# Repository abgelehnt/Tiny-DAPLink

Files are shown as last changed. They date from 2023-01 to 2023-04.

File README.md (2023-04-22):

# Tiny-DAPLink

> 小巧的使用CH552实现的DAPLink

详见[Tiny-DAPLink：开源CH552实现的CMSIS-DAP v2升级版](https://whycan.com/t_9365.html)

## 硬件设计

1. 下载按键需要超级小的两脚小龟按键，如果不重复下载调试，可以不焊
2. 整体需要包热缩管进行绝缘，不然手汗会造成数据异常

## DAT命令列表

使用任意串口工具发送特定的命令即可对Tiny-DAPLink进行相应的设置。

| 命令 | 描述 |
|:---|:---|
| DAT+RST | 重启调试器 |
| DAT+IAP | 进入调试器固件下载模式 |
| DAT+KEY? | 查询电容键盘映射的按键 |
| DAT+KEY=XX | 更改电容键盘映射的按键[USB CDC键盘键值表](3.Docs/Keyboard_HID.txt) |
| DAT+KEY=FF | 关闭电容键盘功能 |
| DAT+AUTHOR? | 查询作者信息 |
| DAT+KEY_FLASH | 刷新电容按键参数 |
| DAT+KEY_VALUE | 查看电容按键参数 |

## 注意事项

1. 一些不合格的数据线会使Type C接口外壳对地短路，使电容按键失效

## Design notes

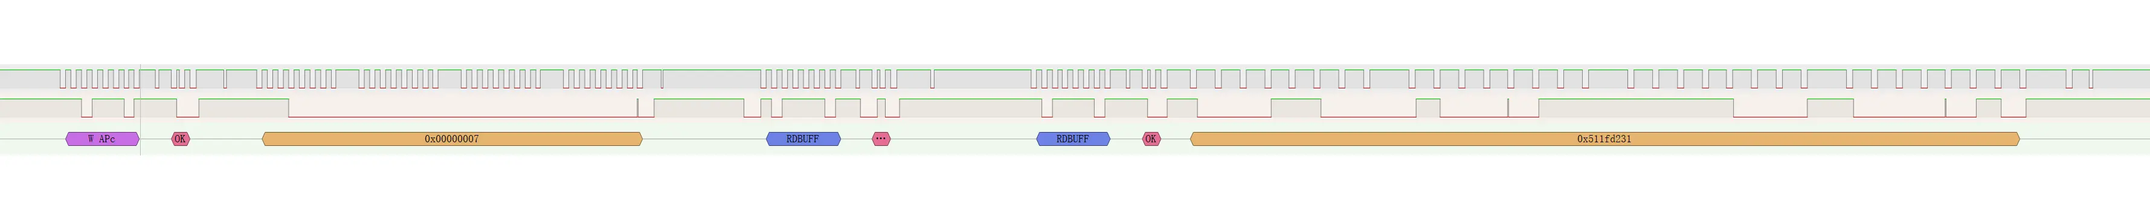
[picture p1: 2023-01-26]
4.Waves/d单次刷写.webp

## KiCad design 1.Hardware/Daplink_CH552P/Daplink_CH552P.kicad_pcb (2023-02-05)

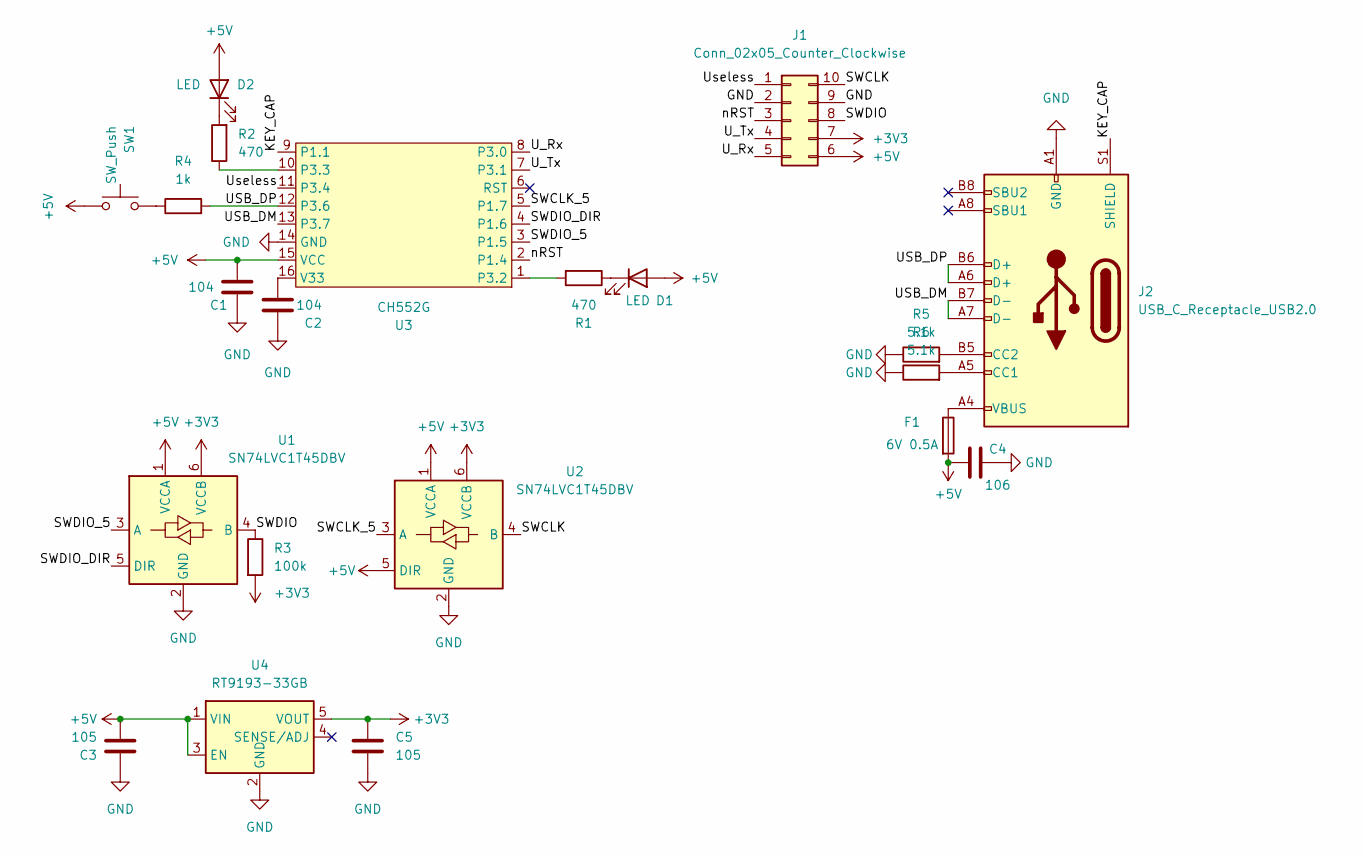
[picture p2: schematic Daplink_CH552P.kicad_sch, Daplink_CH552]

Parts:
C1, C2: 104; C_0603_1608Metric
C3, C5: 105; C_0603_1608Metric
C4: 106; C_0805_2012Metric
D1, D2: LED; LED_0603_1608Metric
F1: 6V 0.5A; Fuse_0603_1608Metric
J1: Conn_02x05_Counter_Clockwise; Connector_2.54mm_2_5P_SMD
J2: USB_C_Receptacle_USB2.0; USB_C_Receptacle_HRO_TYPE-C-31-M-12
R1, R2: 470; R_0603_1608Metric
R3: 100k; R_0603_1608Metric
R4: 1k; R_0603_1608Metric
R5, R6: 5.1k; R_0603_1608Metric
SW1: SW_Push; SW_SPST_B3U-1000P
U1, U2: SN74LVC1T45DBV; SOT-23-6
U3: CH552G; SOP-16_3.9x9.9mm_P1.27mm
U4: RT9193-33GB; TSOT-23-5

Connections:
+3V3: C5.2, J1.7, R3.2, U1.6 (VCCB), U2.6 (VCCB), U4.5 (VOUT)
+5V: C1.1, C3.1, C4.1, D1.2 (A), D2.2 (A), F1.2, J1.6, SW1.1, U1.1 (VCCA), U2.1 (VCCA), U2.5 (DIR), U3.15 (VCC), U4.1 (VIN), U4.3 (EN)
/KEY_CAP: J2.S1 (SHIELD), U3.9 (P1.1)
/SWCLK: J1.10, U2.4 (B)
/SWCLK_5: U2.3 (A), U3.5 (P1.7)
/SWDIO: J1.8, R3.1, U1.4 (B)
/SWDIO_5: U1.3 (A), U3.3 (P1.5)
/SWDIO_DIR: U1.5 (DIR), U3.4 (P1.6)
/USB_DM: J2.A7 (D-), J2.B7 (D-), U3.13 (P3.7)
/USB_DP: J2.A6 (D+), J2.B6 (D+), R4.2, U3.12 (P3.6)
/U_Rx: J1.5, U3.8 (P3.0)
/U_Tx: J1.4, U3.7 (P3.1)
/Useless: J1.1, U3.11 (P3.4)
/nRST: J1.3, U3.2 (P1.4)
GND: C1.2, C2.1, C3.2, C4.2, C5.1, J1.2, J1.9, J2.A1 (GND), J2.A12 (GND), J2.B1 (GND), J2.B12 (GND), R5.1, R6.1, U1.2 (GND), U2.2 (GND), U3.14 (GND), U4.2 (GND)
unnamed: C2.2, U3.16 (V33)
unnamed: D1.1 (K), R1.1
unnamed: D2.1 (K), R2.2
unnamed: F1.1, J2.A4 (VBUS), J2.A9 (VBUS), J2.B4 (VBUS), J2.B9 (VBUS)
unnamed: J2.A5 (CC1), R6.2
unnamed: J2.B5 (CC2), R5.2
unnamed: R1.2, U3.1 (P3.2)
unnamed: R2.1, U3.10 (P3.3)
unnamed: R4.1, SW1.2

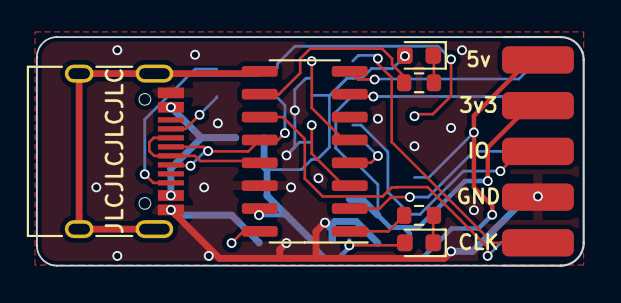
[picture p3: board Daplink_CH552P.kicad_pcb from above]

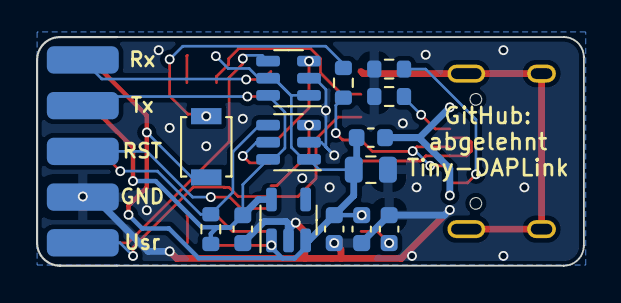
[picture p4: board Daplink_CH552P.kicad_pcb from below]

Board: 2 copper layers, 30.4 x 12.7 mm, 21 parts (15 on the bottom side), 24 nets.

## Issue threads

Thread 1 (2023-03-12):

电平转换电路简化的可能性

Maxwelltoo, 2023-03-12:
CH552系列芯片本身是支持3.3V输入的，直接将稳压输出的3.3V接入VCC，应该就可以省去两个SN74LVC1T45DBV，去掉SWDIO_DIR引脚。
考虑到接入IO的LED和键盘功能并非必须，是否可能将这些引脚全部省下来，进一步简化电路，使用更小封装的CH552E（刚好只有10个引脚）？

abgelehnt, 2023-03-13:
使用CH552E的话，串口引脚会和SPI引脚冲突（时序刷写用到了SPI）
如果退一步，不使用SPI加速刷写的话，使用3.3V电源输入的串口不支持115200波特率传输（16MHz主频），作为最常用的串口波特率，不支持的话整个串口功能都残废了。

Closed 2023-03-16.

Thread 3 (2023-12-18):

openocd 无法识别这个daplink

Retuze, 2023-12-18:
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

Retuze, 2023-12-18:
使用的硬件是梁山派 [daplink下载器](https://oshwhub.com/lengyuefeng/a7c57e6d86bd47789178df3fda9219dc)，使用原梁山派 daplink 固件在keil,openocd,pyocd均可识别、烧录，现使用本固件keil和pyocd能识别但是无法烧录，openocd 找不到daplink

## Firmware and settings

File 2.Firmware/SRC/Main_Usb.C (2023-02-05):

#include "CH552.H"
#include "Debug.H"
#include "DAP.h"
#include "Uart.h"
#include "Timer.H"
#include "AT.h"
#include "TouchKey.H"
#include "Keyboard.h"
#include "DataFlash.H"

#define Fullspeed 1
#define WINUSB 1
#define THIS_ENDP0_SIZE 64
#define ENDP4_IN_SIZE 8

UINT8X Ep0Buffer[THIS_ENDP0_SIZE] _at_ 0x0000;  //端点0 OUT&IN缓冲区，必须是偶地址

// EP1: UART
// extern UINT8X Uart_TxBuff0[]; // 端点1 OUT&IN 双缓冲区，长度0x100
// UINT8X Ep1BufferO[THIS_ENDP0_SIZE] _at_ 0x0040; //端点1 OUT双缓冲区,必须是偶地址 Not Change!!!!!!
// UINT8X Ep1BufferI[THIS_ENDP0_SIZE] _at_ 0x0080; //端点1 IN双缓冲区,必须是偶地址 Not Change!!!!!!

// EP2: DAP-CMD
//100,140,180,1C0
UINT8X Ep2BufferO[4 * THIS_ENDP0_SIZE] _at_ 0x0100; //端点2 OUT缓冲区

// EP3: DAP-ASK
//200,240,280,2C0
UINT8X Ep3BufferI[4 * THIS_ENDP0_SIZE] _at_ 0x0200; //端点3 IN双缓冲区,必须是偶地址

UINT8X Ep4Buffer[ENDP4_IN_SIZE+2] _at_ 0x0040; //端点4 IN双缓冲区,必须是偶地址

BOOL DAP_LED_BUSY;

UINT8I Ep2Oi, Ep2Oo;            //OUT 索引
UINT8I Ep3Ii, Ep3Io;            //IN 索引
UINT8I Ep3Is[DAP_PACKET_COUNT]; //发送包长

PUINT8 pDescr; //USB配置标志
BOOL Endp3Busy = 0;
UINT8I SetupReq, SetupLen, Ready, Count, UsbConfig;
#define UsbSetupBuf ((PUSB_SETUP_REQ)Ep0Buffer)

UINT8C DevDesc[] =
{
    0x12, 0x01, 0x10, 0x02, 0xEF, 0x02, 0x01, THIS_ENDP0_SIZE,
    0x28, 0x0D, 0x04, 0x02, 0x00, 0x01, 0x01, 0x02,
    0x03, 0x01
};
UINT8C CfgDesc[] =
{
//					wTotalLength	bNumInterfaces
    0x09,	0x02,	99,		0x00,	0x03,	0x01,	0x00,	0x80,	0xfa, //配置描述符
//	0x09,	0x02,	74,		0x00,	0x02,	0x01,	0x00,	0x80,	0xfa, //配置描述符

    //DAP
//			描述符	编号				端点数量 类码		子类码	协议码	字符串索引
    0x09,	0x04,	0x00,	0x00,	0x02,	0xff,	0x00,	0x00,	0x04, //接口描述符
//					端点号	Bulk	最大包大小		bInterval
    0x07,	0x05,	0x02,	0x02,	0x40,	0x00,	0x00, //端点描述符
    0x07,	0x05,	0x83,	0x02,	0x40,	0x00,	0x00,

	//CDC
    0x09,	0x04,	0x01,	0x00,	0x02,	0x02,	0x02,	0x01,	0x05,
	0x05,	0x24,	0x00,	0x10,	0x01,
    0x05,	0x24,	0x01,	0x00,	0x01,
    0x04,	0x24,	0x02,	0x02,
    0x05,	0x24,	0x06,	0x00,	0x01,
    0x07,	0x05,	0x01,	0x02,	0x40,	0x00,	0x00,
    0x07,	0x05,	0x81,	0x02,	0x40,	0x00,	0x00,

	// Keyboard
	0x09,	0x04,	0x02,	0x00,	0x01,	0x03,	0x01,	0x01,	0x06,	//接口描述符,键盘
	0x09,	0x21,	0x11,	0x01,	0x00,	0x01,	0x22,	0x3e,	0x00,	//HID类描述符
	0x07,	0x05,	0x84,	0x03,	8,		0x00,	0x20,					//端点描述符
};

UINT16I USB_STATUS = 0;
//cdc参数
UINT8I LineCoding[7] = {0x00, 0xe1, 0x00, 0x00, 0x00, 0x00, 0x08}; //初始化波特率为57600，1停止位，无校验，8数据位。

/*字符串描述符 略*/
// 语言描述符
UINT8C MyLangDescr[] = {0x04, 0x03, 0x09, 0x04};
// 厂家信息:ARM
UINT8C MyManuInfo[] = {0x08, 0x03, 'A', 0x00, 'R', 0x00, 'M', 0x00};
// 产品信息: DAPLink CMSIS-DAP
UINT8C MyProdInfo[] =
{
    36,
    0x03,
    'D', 0, 'A', 0, 'P', 0, 'L', 0, 'i', 0, 'n', 0, 'k', 0, ' ', 0,
    'C', 0, 'M', 0, 'S', 0, 'I', 0, 'S', 0, '-', 0, 'D', 0, 'A', 0,
    'P', 0
};

// 设备序列号
UINT8X SerNumber[] =
{
    0x12,
    0x03,
    '0', 0, '0', 0, '0', 0, '0', 0, '0', 0, '0', 0, '0', 0, '0', 0,
};

// 接口: CMSIS-DAP v2
UINT8C MyInterface[] =
{
    26,
    0x03,
    'C', 0, 'M', 0, 'S', 0, 'I', 0, 'S', 0, '-', 0, 'D', 0, 'A', 0,
    'P', 0, ' ', 0, 'v', 0, '2', 0
};
// 接口：USB-CDC
UINT8C CDC_String[] =
{
    30,
    0x03,
    'D', 0, 'A', 0, 'P', 0, 'L', 0, 'i', 0, 'n', 0, 'k', 0, '-', 0, 
	'C', 0, 'D', 0, 'C', 0, 'E', 0, 'x', 0, 't', 0
};
// 接口：DAPLink-Keyboard
UINT8C Keyboard_String[] =
{
    34,
    0x03,
    'D', 0, 'A', 0, 'P', 0, 'L', 0, 'i', 0, 'n', 0, 'k', 0, '-', 0, 
	'K', 0, 'e', 0, 'y', 0, 'b', 0, 'o', 0, 'a', 0, 'r', 0, 'd', 0
};

UINT8C USB_BOSDescriptor[] =
{
    0x05,                                      /* bLength */
    0x0F,                                      /* bDescriptorType */
    0x28, 0x00,                                /* wTotalLength */
    0x02,                                      /* bNumDeviceCaps */
    0x07, 0x10, 0x02, 0x00, 0x00, 0x00, 0x00,
    0x1C,                                      /* bLength */
    0x10,                                      /* bDescriptorType */
    0x05,                                      /* bDevCapabilityType */
    0x00,                                      /* bReserved */
    0xDF, 0x60, 0xDD, 0xD8,                    /* PlatformCapabilityUUID */
    0x89, 0x45, 0xC7, 0x4C,
    0x9C, 0xD2, 0x65, 0x9D,
    0x9E, 0x64, 0x8A, 0x9F,
    0x00, 0x00, 0x03, 0x06,    /* >= Win 8.1 *//* dwWindowsVersion*/
    0xAA, 0x00,                                /* wDescriptorSetTotalLength */
    0x20,                                      /* bVendorCode */
    0x00                                       /* bAltEnumCode */
};

UINT8C WINUSB_Descriptor[] =
{
    0x0A, 0x00,                                 /* wLength */
    0x00, 0x00,                                 /* wDescriptorType */
    0x00, 0x00, 0x03, 0x06,                     /* dwWindowsVersion*/
    0xAA, 0x00,                                 /* wDescriptorSetTotalLength */
    /* ... */
    0x08, 0x00,
    0x02, 0x00,
    0x00, 0x00,
    0xA0, 0x00,
    /* ... */
    0x14, 0x00,                                 /* wLength */
    0x03, 0x00,                                 /* wDescriptorType */
    'W', 'I', 'N', 'U', 'S', 'B', 0, 0,         /* CompatibleId*/
    0, 0, 0, 0, 0, 0, 0, 0,                     /* SubCompatibleId*/
    0x84, 0x00,                                 /* wLength */
    0x04, 0x00,                                 /* wDescriptorType */
    0x07, 0x00,                                 /* wPropertyDataType */
    0x2A, 0x00,                                 /* wPropertyNameLength */
    'D', 0, 'e', 0, 'v', 0, 'i', 0, 'c', 0, 'e', 0,
    'I', 0, 'n', 0, 't', 0, 'e', 0, 'r', 0, 'f', 0, 'a', 0, 'c', 0, 'e', 0,
    'G', 0, 'U', 0, 'I', 0, 'D', 0, 's', 0, 0, 0,
    0x50, 0x00,                                 /* wPropertyDataLength */
    '{', 0,
    'C', 0, 'D', 0, 'B', 0, '3', 0, 'B', 0, '5', 0, 'A', 0, 'D', 0, '-', 0,
    '2', 0, '9', 0, '3', 0, 'B', 0, '-', 0,
    '4', 0, '6', 0, '6', 0, '3', 0, '-', 0,
    'A', 0, 'A', 0, '3', 0, '6', 0, '-',
    0, '1', 0, 'A', 0, 'A', 0, 'E', 0, '4', 0, '6', 0, '4', 0, '6', 0, '3', 0, '7', 0, '7', 0, '6', 0,
    '}', 0, 0, 0, 0, 0,
};

/*HID类报表描述符*/
UINT8C KeyRepDesc[62] = {
	0x05,0x01,0x09,0x06,0xA1,0x01,0x05,0x07,
	0x19,0xe0,0x29,0xe7,0x15,0x00,0x25,0x01,
	0x75,0x01,0x95,0x08,0x81,0x02,0x95,0x01,
	0x75,0x08,0x81,0x01,0x95,0x03,0x75,0x01,
	0x05,0x08,0x19,0x01,0x29,0x03,0x91,0x02,
	0x95,0x05,0x75,0x01,0x91,0x01,0x95,0x06,
	0x75,0x08,0x26,0xff,0x00,0x05,0x07,0x19,
	0x00,0x29,0x91,0x81,0x00,0xC0
};

/*******************************************************************************
* Function Name  : USBDeviceInit()
* Description    : USB设备模式配置,设备模式启动，收发端点配置，中断开启
* Input          : None
* Output         : None
* Return         : None
*******************************************************************************/
void USBDeviceInit()
{
    IE_USB = 0;
    USB_CTRL = 0x00;        // 先设定USB设备模式
    UDEV_CTRL = bUD_PD_DIS; // 禁止DP/DM下拉电阻
#ifndef Fullspeed
    UDEV_CTRL |= bUD_LOW_SPEED; //选择低速1.5M模式
    USB_CTRL |= bUC_LOW_SPEED;
#else
    UDEV_CTRL &= ~bUD_LOW_SPEED; //选择全速12M模式，默认方式
    USB_CTRL &= ~bUC_LOW_SPEED;
#endif

    UEP0_DMA = Ep0Buffer;                                      //端点0数据传输地址
    UEP4_1_MOD &= ~(bUEP4_RX_EN | bUEP4_TX_EN);                //端点0单64字节收发缓冲区
    UEP0_CTRL = UEP_R_RES_ACK | UEP_T_RES_NAK;                 //OUT事务返回ACK，IN事务返回NAK

    UEP1_DMA = Uart_TxBuff0;									//端点1数据传输地址
    UEP4_1_MOD |= bUEP1_TX_EN | bUEP1_RX_EN;					//端点1发送接收使能
    UEP4_1_MOD |= bUEP1_BUF_MOD;								//端点1收发各双64字节缓冲区
    UEP1_CTRL = bUEP_AUTO_TOG | UEP_T_RES_NAK | UEP_R_RES_ACK; 					//端点1，IN事务返回NAK，OUT返回ACK

    UEP2_DMA = Ep2BufferO;                                     //端点2数据传输地址
    UEP3_DMA = Ep3BufferI;                                     //端点2数据传输地址
    UEP2_3_MOD |= (bUEP3_TX_EN | bUEP2_RX_EN);                   //端点2发送接收使能
    UEP2_3_MOD &= ~(bUEP2_BUF_MOD | bUEP3_BUF_MOD);            //端点2收发各64字节缓冲区
    UEP2_CTRL = bUEP_AUTO_TOG | UEP_T_RES_NAK | UEP_R_RES_ACK; //端点2自动翻转同步标志位，IN事务返回NAK，OUT返回ACK
    UEP3_CTRL = bUEP_AUTO_TOG | UEP_T_RES_NAK | UEP_R_RES_NAK;//端点3自动翻转同步标志位，IN事务返回NAK，OUT返回NACK

    UEP4_1_MOD |= bUEP4_TX_EN; // 端点4发送使能

    USB_DEV_AD = 0x00;
    USB_CTRL |= bUC_DEV_PU_EN | bUC_INT_BUSY | bUC_DMA_EN; // 启动USB设备及DMA，在中断期间中断标志未清除前自动返回NAK
    UDEV_CTRL |= bUD_PORT_EN;                              // 允许USB端口
    USB_INT_FG = 0xFF;                                     // 清中断标志
    USB_INT_EN = bUIE_SUSPEND | bUIE_TRANSFER | bUIE_BUS_RST;
    IE_USB = 1;
}

typedef void( *goISP)( void );
goISP ISP_ADDR=0x3800;

void DeviceInterrupt(void) interrupt INT_NO_USB //USB中断服务程序,使用寄存器组1
{
    UINT8 len;
    if (UIF_TRANSFER) //USB传输完成标志
    {
        switch (USB_INT_ST & (MASK_UIS_TOKEN | MASK_UIS_ENDP))
        {
        case UIS_TOKEN_OUT | 2: //endpoint 2# 端点批量下传 DAP-CMD
            if (U_TOG_OK)         // 不同步的数据包将丢弃
            {
                Ep2Oi += 64;
                UEP2_DMA_L = Ep2Oi;
            }
            break;

        case UIS_TOKEN_IN | 3: //endpoint 3# 端点批量上传 DAP_ASK
            Endp3Busy = 0;
            UEP3_T_LEN = 0;      //预使用发送长度一定要清空
            UEP3_CTRL = UEP3_CTRL & ~ MASK_UEP_T_RES | UEP_T_RES_NAK; //默认应答NAK
            break;

        case UIS_TOKEN_IN | 1: //endpoint 1# 端点批量上传 CDC
			UEP1_T_LEN = 0;
			UEP1_CTRL = UEP1_CTRL & ~ MASK_UEP_T_RES | UEP_T_RES_NAK;
			USB_CDC_PushData();
            break;

        case UIS_TOKEN_OUT | 1: //endpoint 1# 端点批量下传 CDC
            if (U_TOG_OK)         // 不同步的数据包将丢弃
            {
				USB_CDC_GetData();
            }
            break;
		case UIS_TOKEN_IN | 4: //endpoint 1# 端点中断上传
			UEP4_T_LEN = 0;
			UEP4_CTRL ^= bUEP_T_TOG;
			UEP4_CTRL = UEP4_CTRL & ~ MASK_UEP_T_RES | UEP_T_RES_NAK;           //默认应答NAK
			Keyboard_Flag = 1;
			break;

        case UIS_TOKEN_SETUP | 0: //SETUP事务
            len = USB_RX_LEN;
            if (len == (sizeof(USB_SETUP_REQ)))
            {
                SetupLen = UsbSetupBuf->wLengthL;
                if (UsbSetupBuf->wLengthH)
                    SetupLen = 0xFF; // 限制总长度
                len = 0;           // 默认为成功并且上传0长度
                SetupReq = UsbSetupBuf->bRequest;
                switch (UsbSetupBuf->bRequestType & USB_REQ_TYP_MASK)
                {
					case USB_REQ_TYP_STANDARD:
						switch (SetupReq) //请求码
						{
							case USB_GET_DESCRIPTOR:
								switch (UsbSetupBuf->wValueH){
								case 1:             //设备描述符
									pDescr = DevDesc; //把设备描述符送到要发送的缓冲区
									len = sizeof(DevDesc);
									break;
								case 2:             //配置描述符
									pDescr = CfgDesc; //把设备描述符送到要发送的缓冲区
									len = sizeof(CfgDesc);
									break;
								case 3: // 字符串描述符
									switch (UsbSetupBuf->wValueL)
									{
										case 0:
											pDescr = (PUINT8)(&MyLangDescr[0]);
											len = sizeof(MyLangDescr);
											break;
										case 1:
											pDescr = (PUINT8)(&MyManuInfo[0]);
											len = sizeof(MyManuInfo);
											break;
										case 2:
											pDescr = (PUINT8)(&MyProdInfo[0]);
											len = sizeof(MyProdInfo);
											break;
										case 3:
											HEX_TO_ASCII(SerNumber[2],*(UINT8C *)(0x3FFC)/16);
											HEX_TO_ASCII(SerNumber[4],*(UINT8C *)(0x3FFC)%16);
											HEX_TO_ASCII(SerNumber[6],*(UINT8C *)(0x3FFD)/16);
											HEX_TO_ASCII(SerNumber[8],*(UINT8C *)(0x3FFD)%16);
											
											HEX_TO_ASCII(SerNumber[10],*(UINT8C *)(0x3FFE)/16);
											HEX_TO_ASCII(SerNumber[12],*(UINT8C *)(0x3FFE)%16);
											HEX_TO_ASCII(SerNumber[14],*(UINT8C *)(0x3FFF)/16);
											HEX_TO_ASCII(SerNumber[16],*(UINT8C *)(0x3FFF)%16);
											
											pDescr = SerNumber;
											len = sizeof(SerNumber);
											break;
										case 4:
											pDescr = (PUINT8)(&MyInterface[0]);
											len = sizeof(MyInterface);
											break;
										case 5:
											pDescr = (PUINT8)(&CDC_String[0]);
											len = sizeof(CDC_String);
											break;
										case 6:
											pDescr = (PUINT8)(&Keyboard_String[0]);
											len = sizeof(Keyboard_String);
											break;
										default:
											len = 0xFF; // 不支持的字符串描述符
											break;
									}
									break;
								case 15:
									pDescr = (PUINT8)(&USB_BOSDescriptor[0]);
									len = sizeof(USB_BOSDescriptor);
									break;
								case 0x22:                                          //报表描述符
									if(UsbSetupBuf->wIndexL == 2)                   //接口0报表描述符
									{
										pDescr = KeyRepDesc;                        //数据准备上传
										len = sizeof(KeyRepDesc);
									}
									else
									{
										len = 0xff;           //本程序只有2个接口，这句话正常不可能执行
									}
									break;
								default:
									len = 0xff; //不支持的命令或者出错
									break;
							}
							break;
						case USB_SET_ADDRESS:
							SetupLen = UsbSetupBuf->wValueL; //暂存USB设备地址
							break;
						case USB_GET_CONFIGURATION:
							Ep0Buffer[0] = UsbConfig;
							if (SetupLen >= 1)
							{
								len = 1;
							}
							break;
						case USB_SET_CONFIGURATION:
							UsbConfig = UsbSetupBuf->wValueL;
							if (UsbConfig)
							{
								Ready = 1; //set config命令一般代表usb枚举完成的标志
							}
							break;
						case 0x0A:
							break;
						case USB_CLEAR_FEATURE:                                                       //Clear Feature
							if ((UsbSetupBuf->bRequestType & USB_REQ_RECIP_MASK) == USB_REQ_RECIP_ENDP) // 端点
							{
								switch (UsbSetupBuf->wIndexL)
								{
								case 0x82:
									UEP2_CTRL = UEP2_CTRL & ~(bUEP_T_TOG | MASK_UEP_T_RES) | UEP_T_RES_NAK;
									break;
								case 0x81:
									UEP1_CTRL = UEP1_CTRL & ~(bUEP_T_TOG | MASK_UEP_T_RES) | UEP_T_RES_NAK;
									break;
								case 0x02:
									UEP2_CTRL = UEP2_CTRL & ~(bUEP_R_TOG | MASK_UEP_R_RES) | UEP_R_RES_ACK;
									break;
								default:
									len = 0xFF; // 不支持的端点
									break;
								}
							}
							else
							{
								len = 0xFF; // 不是端点不支持
							}
							break;
						case USB_SET_FEATURE:                             /* Set Feature */
							if ((UsbSetupBuf->bRequestType & 0x1F) == 0x00) /* 设置设备 */
							{
								if ((((UINT16)UsbSetupBuf->wValueH << 8) | UsbSetupBuf->wValueL) == 0x01)
								{
									if (CfgDesc[7] & 0x20)
									{
										/* 设置唤醒使能标志 */
									}
									else
									{
										len = 0xFF; /* 操作失败 */
									}
								}
								else
								{
									len = 0xFF; /* 操作失败 */
								}
							}
							else if ((UsbSetupBuf->bRequestType & 0x1F) == 0x02) /* 设置端点 */
							{
								if ((((UINT16)UsbSetupBuf->wValueH << 8) | UsbSetupBuf->wValueL) == 0x00)
								{
									switch (((UINT16)UsbSetupBuf->wIndexH << 8) | UsbSetupBuf->wIndexL)
									{
									case 0x82:
										UEP2_CTRL = UEP2_CTRL & (~bUEP_T_TOG) | UEP_T_RES_STALL; /* 设置端点2 IN STALL */
										break;
									case 0x02:
										UEP2_CTRL = UEP2_CTRL & (~bUEP_R_TOG) | UEP_R_RES_STALL; /* 设置端点2 OUT Stall */
										break;
									case 0x81:
										UEP1_CTRL = UEP1_CTRL & (~bUEP_T_TOG) | UEP_T_RES_STALL; /* 设置端点1 IN STALL */
										break;
									default:
										len = 0xFF; /* 操作失败 */
										break;
									}
								}
								else
								{
									len = 0xFF; /* 操作失败 */
								}
							}
							else
							{
								len = 0xFF; /* 操作失败 */
							}
							break;
						case USB_GET_STATUS:
							pDescr = (PUINT8)&USB_STATUS;
							if (SetupLen >= 2)
							{
								len = 2;
							}
							else
							{
								len = SetupLen;
							}
							break;
						default:
							len = 0xff; //操作失败
							break;
                    }
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
void main(void)
{
    CfgFsys();   //CH559时钟选择配置
    mDelaymS(5); //修改主频等待内部晶振稳定,必加
   
    USBDeviceInit(); //USB设备模式初始化
	UART_Setup();
    P1_MOD_OC = P1_MOD_OC & ~(1 << 4);
    P1_DIR_PU = P1_DIR_PU | (1 << 4);
    P1_MOD_OC = P1_MOD_OC & ~(1 << 5);
    P1_DIR_PU = P1_DIR_PU | (1 << 5);
	
	//Timer2_Init();
	TK_Init( BIT4,1,0 );
	ReadDataFlash(0,1,&TargetKey);
	memset(Ep4Buffer,0,8);

	SAFE_MOD = 0x55;
	SAFE_MOD = 0xAA;
	WAKE_CTRL = bWAK_BY_USB | bWAK_RXD0_LO;	//USB or RXD0 can wake it up
	
	
    EA = 1;          //允许单片机中断
    UEP1_T_LEN = 0;  //预使用发送长度一定要清空
    UEP2_T_LEN = 0;  //预使用发送长度一定要清空
    Ready = 0;

    Ep2Oi = 0;
    Ep2Oo = 0;
    Ep3Ii = 0;
    Ep3Io = 0;
    Endp3Busy = 0;
	DAP_LED_BUSY = 0;
	LED_Timer = 0;
	

	
    while (!UsbConfig) {;};

    while (1)
    {
        DAP_Thread();

        if (Endp3Busy != 1 && Ep3Ii != Ep3Io){
            Endp3Busy = 1;
            UEP3_T_LEN = Ep3Is[0];//Ep3Io>>6];
            UEP3_DMA_L = Ep3Io;
            
            UEP3_CTRL = UEP3_CTRL & ~MASK_UEP_T_RES | UEP_T_RES_ACK; //有数据时上传数据并应答ACK
            Ep3Io += 64;
        }
		
		
		if(DAP_LED_BUSY)
		{
			LED = 1;
		}
		else
		{
			LED_Timer++;
			if(LED_Timer==0x09)
			{
				LED = 0;
			}else if(LED_Timer==0xFF)
			{
				LED_Timer = 0;
				LED = 1;
			}	
			TK_Measure();
		}

		LED2 = XBUS_AUX & (bUART0_TX | bUART0_RX);

		if(TO_IAP) {
			EA = 0;
			USB_CTRL = 0;
			UDEV_CTRL = 0x80;
			mDelaymS(100);
			(ISP_ADDR)();
		}
    }
}

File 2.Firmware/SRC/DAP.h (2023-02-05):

/*
 * Copyright (c) 2013-2017 ARM Limited. All rights reserved.
 *
 * SPDX-License-Identifier: Apache-2.0
 *
 * Licensed under the Apache License, Version 2.0 (the License); you may
 * not use this file except in compliance with the License.
 * You may obtain a copy of the License at
 *
 * www.apache.org/licenses/LICENSE-2.0
 *
 * Unless required by applicable law or agreed to in writing, software
 * distributed under the License is distributed on an AS IS BASIS, WITHOUT
 * WARRANTIES OR CONDITIONS OF ANY KIND, either express or implied.
 * See the License for the specific language governing permissions and
 * limitations under the License.
 *
 * ----------------------------------------------------------------------
 *
 * $Date:        1. December 2017
 * $Revision:    V2.0.0
 *
 * Project:      CMSIS-DAP Include
 * Title:        DAP.h Definitions
 *
 *---------------------------------------------------------------------------*/

#ifndef __DAP_H__
#define __DAP_H__

#include "CH552.H"
#include <stdio.h>
#include <string.h>
#include <intrins.h>

// DAP Firmware Version
#define DAP_FW_VER "2.0.0"

// DAP Command IDs
#define ID_DAP_Info 0x00U
#define ID_DAP_HostStatus 0x01U
#define ID_DAP_Connect 0x02U
#define ID_DAP_Disconnect 0x03U
#define ID_DAP_TransferConfigure 0x04U
#define ID_DAP_Transfer 0x05U
#define ID_DAP_TransferBlock 0x06U
#define ID_DAP_TransferAbort 0x07U
#define ID_DAP_WriteABORT 0x08U
#define ID_DAP_Delay 0x09U
#define ID_DAP_ResetTarget 0x0AU
#define ID_DAP_SWJ_Pins 0x10U
#define ID_DAP_SWJ_Clock 0x11U
#define ID_DAP_SWJ_Sequence 0x12U
#define ID_DAP_SWD_Configure 0x13U
#define ID_DAP_SWD_Sequence 0x1DU
#define ID_DAP_JTAG_Sequence 0x14U
#define ID_DAP_JTAG_Configure 0x15U
#define ID_DAP_JTAG_IDCODE 0x16U
#define ID_DAP_SWO_Transport 0x17U
#define ID_DAP_SWO_Mode 0x18U
#define ID_DAP_SWO_Baudrate 0x19U
#define ID_DAP_SWO_Control 0x1AU
#define ID_DAP_SWO_Status 0x1BU
#define ID_DAP_SWO_ExtendedStatus 0x1EU
#define ID_DAP_SWO_Data 0x1CU

#define ID_DAP_QueueCommands 0x7EU
#define ID_DAP_ExecuteCommands 0x7FU

// DAP Vendor Command IDs
#define ID_DAP_Vendor0 0x80U
#define ID_DAP_Vendor1 0x81U
#define ID_DAP_Vendor2 0x82U
#define ID_DAP_Vendor3 0x83U
#define ID_DAP_Vendor4 0x84U
#define ID_DAP_Vendor5 0x85U
#define ID_DAP_Vendor6 0x86U
#define ID_DAP_Vendor7 0x87U
#define ID_DAP_Vendor8 0x88U
#define ID_DAP_Vendor9 0x89U
#define ID_DAP_Vendor10 0x8AU
#define ID_DAP_Vendor11 0x8BU
#define ID_DAP_Vendor12 0x8CU
#define ID_DAP_Vendor13 0x8DU
#define ID_DAP_Vendor14 0x8EU
#define ID_DAP_Vendor15 0x8FU
#define ID_DAP_Vendor16 0x90U
#define ID_DAP_Vendor17 0x91U
#define ID_DAP_Vendor18 0x92U
#define ID_DAP_Vendor19 0x93U
#define ID_DAP_Vendor20 0x94U
#define ID_DAP_Vendor21 0x95U
#define ID_DAP_Vendor22 0x96U
#define ID_DAP_Vendor23 0x97U
#define ID_DAP_Vendor24 0x98U
#define ID_DAP_Vendor25 0x99U
#define ID_DAP_Vendor26 0x9AU
#define ID_DAP_Vendor27 0x9BU
#define ID_DAP_Vendor28 0x9CU
#define ID_DAP_Vendor29 0x9DU
#define ID_DAP_Vendor30 0x9EU
#define ID_DAP_Vendor31 0x9FU

#define ID_DAP_Invalid 0xFFU

// DAP Status Code
#define DAP_OK 0U
#define DAP_ERROR 0xFFU

// DAP ID
#define DAP_ID_VENDOR 1U
#define DAP_ID_PRODUCT 2U
#define DAP_ID_SER_NUM 3U
#define DAP_ID_FW_VER 4U
#define DAP_ID_DEVICE_VENDOR 5U
#define DAP_ID_DEVICE_NAME 6U
#define DAP_ID_CAPABILITIES 0xF0U
#define DAP_ID_TIMESTAMP_CLOCK 0xF1U
#define DAP_ID_SWO_BUFFER_SIZE 0xFDU
#define DAP_ID_PACKET_COUNT 0xFEU
#define DAP_ID_PACKET_SIZE 0xFFU

// DAP Host Status
#define DAP_DEBUGGER_CONNECTED 0U
#define DAP_TARGET_RUNNING 1U

// DAP Port
#define DAP_PORT_AUTODETECT 0U // Autodetect Port
#define DAP_PORT_DISABLED 0U   // Port Disabled (I/O pins in High-Z)
#define DAP_PORT_SWD 1U        // SWD Port (SWCLK, SWDIO) + nRESET
#define DAP_PORT_JTAG 2U       // JTAG Port (TCK, TMS, TDI, TDO, nTRST) + nRESET

// DAP SWJ Pins
#define DAP_SWJ_SWCLK_TCK 0 // SWCLK/TCK
#define DAP_SWJ_SWDIO_TMS 1 // SWDIO/TMS
#define DAP_SWJ_TDI 2       // TDI
#define DAP_SWJ_TDO 3       // TDO
#define DAP_SWJ_nTRST 5     // nTRST
#define DAP_SWJ_nRESET 7    // nRESET

#define DAP_SWJ_SWCLK_TCK_BIT 0x01 // SWCLK/TCK
#define DAP_SWJ_SWDIO_TMS_BIT 0x02 // SWDIO/TMS
#define DAP_SWJ_TDI_BIT 0x04       // TDI
#define DAP_SWJ_TDO_BIT 0x08       // TDO
#define DAP_SWJ_nTRST_BIT 0x20     // nTRST
#define DAP_SWJ_nRESET_BIT 0x80    // nRESET

// DAP Transfer Request
#define DAP_TRANSFER_APnDP (1U << 0)
#define DAP_TRANSFER_RnW (1U << 1)
#define DAP_TRANSFER_A2 (1U << 2)
#define DAP_TRANSFER_A3 (1U << 3)
#define DAP_TRANSFER_MATCH_VALUE (1U << 4)
#define DAP_TRANSFER_MATCH_MASK (1U << 5)
#define DAP_TRANSFER_TIMESTAMP (1U << 7)

// DAP Transfer Response
#define DAP_TRANSFER_OK (1U << 0)
#define DAP_TRANSFER_WAIT (1U << 1)
#define DAP_TRANSFER_FAULT (1U << 2)
#define DAP_TRANSFER_ERROR (1U << 3)
#define DAP_TRANSFER_MISMATCH (1U << 4)

// DAP SWO Trace Mode
#define DAP_SWO_OFF 0U
#define DAP_SWO_UART 1U
#define DAP_SWO_MANCHESTER 2U

// DAP SWO Trace Status
#define DAP_SWO_CAPTURE_ACTIVE (1U << 0)
#define DAP_SWO_CAPTURE_PAUSED (1U << 1)
#define DAP_SWO_STREAM_ERROR (1U << 6)
#define DAP_SWO_BUFFER_OVERRUN (1U << 7)

// Debug Port Register Addresses
#define DP_IDCODE 0x00U    // IDCODE Register (SW Read only)
#define DP_ABORT 0x00U     // Abort Register (SW Write only)
#define DP_CTRL_STAT 0x04U // Control & Status
#define DP_WCR 0x04U       // Wire Control Register (SW Only)
#define DP_SELECT 0x08U    // Select Register (JTAG R/W & SW W)
#define DP_RESEND 0x08U    // Resend (SW Read Only)
#define DP_RDBUFF 0x0CU    // Read Buffer (Read Only)

// JTAG IR Codes
#define JTAG_ABORT 0x08U
#define JTAG_DPACC 0x0AU
#define JTAG_APACC 0x0BU
#define JTAG_IDCODE 0x0EU
#define JTAG_BYPASS 0x0FU

// JTAG Sequence Info
#define JTAG_SEQUENCE_TCK 0x3FU // TCK count
#define JTAG_SEQUENCE_TMS 0x40U // TMS value
#define JTAG_SEQUENCE_TDO 0x80U // TDO capture

// SWD Sequence Info
#define SWD_SEQUENCE_CLK 0x3FU // SWCLK count
#define SWD_SEQUENCE_DIN 0x80U // SWDIO capture

#define DAP_PACKET_COUNT 4
#define DAP_PACKET_SIZE 64 //THIS_ENDP0_SIZE
#define DAP_DEFAULT_PORT DAP_PORT_SWD

sbit RST = P1 ^ 4;
sbit SWK = P1 ^ 7;
sbit SWD = P1 ^ 5;
sbit LED = P3 ^ 3;
sbit LED2 = P3 ^ 2;
sbit DIR_SWD = P1 ^ 6;
extern BOOL DAP_LED_BUSY;

extern UINT8I Ep2Oi;
extern UINT8I Ep2Oo;
extern UINT8I Ep3Ii;
extern UINT8I Ep3Io;
extern UINT8I Ep3Is[];

extern UINT8X Ep2BufferO[];
extern UINT8X Ep3BufferI[];

extern UINT8I turnaround;
extern UINT8I data_phase;
extern UINT8I idle_cycles;

extern void DAP_Thread(void);
extern void PORT_SWD_SETUP(void);
extern void PORT_SWD_OFF(void);
extern void SWD_ResetTarget_Soft(void);
extern UINT8 SWD_Transfer(UINT8 req, char data *datas);
extern void SWJ_Sequence(UINT8I count, const UINT8 *datas);
//extern void SWD_Sequence(UINT8I info, const UINT8 *swdo, UINT8 *swdi);
extern void SWD_IN_Sequence(UINT8I count, UINT8 *swdi);
extern void SWD_Sequence(UINT8I info, const UINT8 *swdo, UINT8 *swdi);

#endif /* __DAP_H__ */

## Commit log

2023-01-10 无关紧要的修改
2023-01-11 串口部分初步可用
2023-01-11 新增AT文件
2023-01-11 串口部分完全写完
2023-01-11 解决可变序列号 串口发现问题：第一次发送的数据错误
2023-01-11 解决串口问题
2023-01-12 找到下载功能无法使用原因：RAM爆了
2023-01-12 找到下载不能用的原因：汇编代码问题，但是串口烂了
2023-01-12 串口问题解决 下载器可以完美使用
2023-01-12 开启睡眠功能
2023-01-13 touch key基本可用
2023-01-13 修正配置描述符
2023-01-13 电容按键做键盘完美运行
2023-01-14 更正IO配置问题：使用推挽输出，准双向口输入
2023-01-21 PSW.PF优化校验速度 使用SPI刷写 数据搬运过程使用汇编优化
2023-01-21 更改项目结构
    [Daplink_CH552P.kicad_pcb, Daplink_CH552P.kicad_sch]
2023-01-23 增加AT+AUTHOR AT+KEY?
2023-01-27 更新帖子地址
2023-02-01 更新调试器硬件（未测试）
    [Daplink_CH552P.kicad_pcb, Daplink_CH552P.kicad_sch]
2023-02-01 更新硬件（未测试）
    [Daplink_CH552P.kicad_pcb]
2023-02-05 清楚不必要文件
2023-02-05 补全3D模型
    [Daplink_CH552P.kicad_pcb]
2023-02-07 添加DTR引脚 开始画第二个板子
    [STM32DemoBoard.kicad_pcb, STM32DemoBoard.kicad_sch]
2023-02-26 使用中断嵌套
2023-04-18 完成电容按键部分
2023-04-18 电容按键阈值可变
2023-04-18 更新README
2023-04-22 优化项目代码 解决了按键更改偶尔不生效的问题
